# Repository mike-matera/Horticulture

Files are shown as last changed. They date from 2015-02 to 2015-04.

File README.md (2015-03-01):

Horticulture
============

Source and documentation for my project working with the Horticulture department at Cabrillo.

Autonomous Light Sensor (c) by Michael Matera

The Autonomous Light Sensor is licensed under a
Creative Commons Attribution-ShareAlike 4.0 International License.

You should have received a copy of the license along with this
work. If not, see <http://creativecommons.org/licenses/by-sa/4.0/>. 

Attributions

The PCB contains footprints from the SparkFun Eagle library. 
  https://github.com/sparkfun/SparkFun-Eagle-Libraries

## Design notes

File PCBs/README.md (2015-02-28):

This directory contains the Eagle shematic and PCB files. 

The bill of materials for the PCB can be found here: 
https://docs.google.com/spreadsheets/d/1OfI_GfA84AMtYy2GsPmqO_wkKgt9htvCScB73qxKzeg/edit?usp=sharing

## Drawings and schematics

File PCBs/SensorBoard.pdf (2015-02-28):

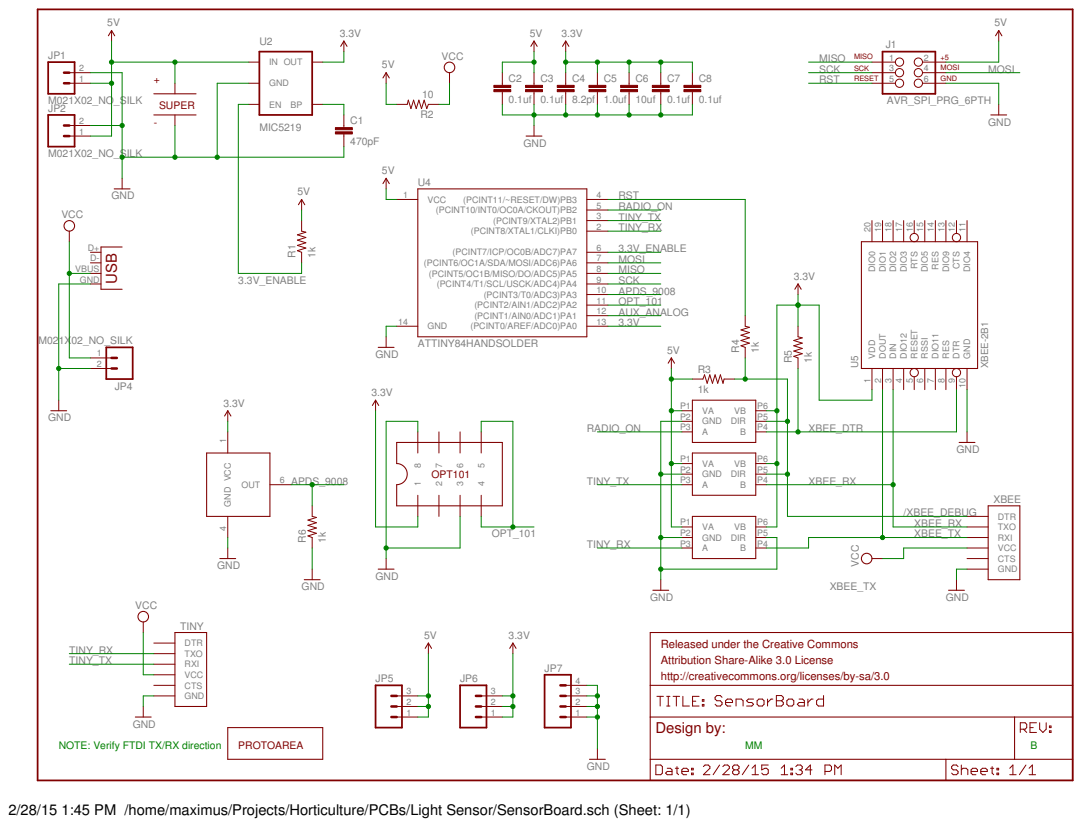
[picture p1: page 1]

Released under the Creative Commons Attribution Share-Alike 3.0 License

http://creativecommons.org/licenses/by-sa/3.0

2/28/15 1:45 PM /home/maximus/Projects/Horticulture/PCBs/Light Sensor/SensorBoard.sch (Sheet: 1/1)

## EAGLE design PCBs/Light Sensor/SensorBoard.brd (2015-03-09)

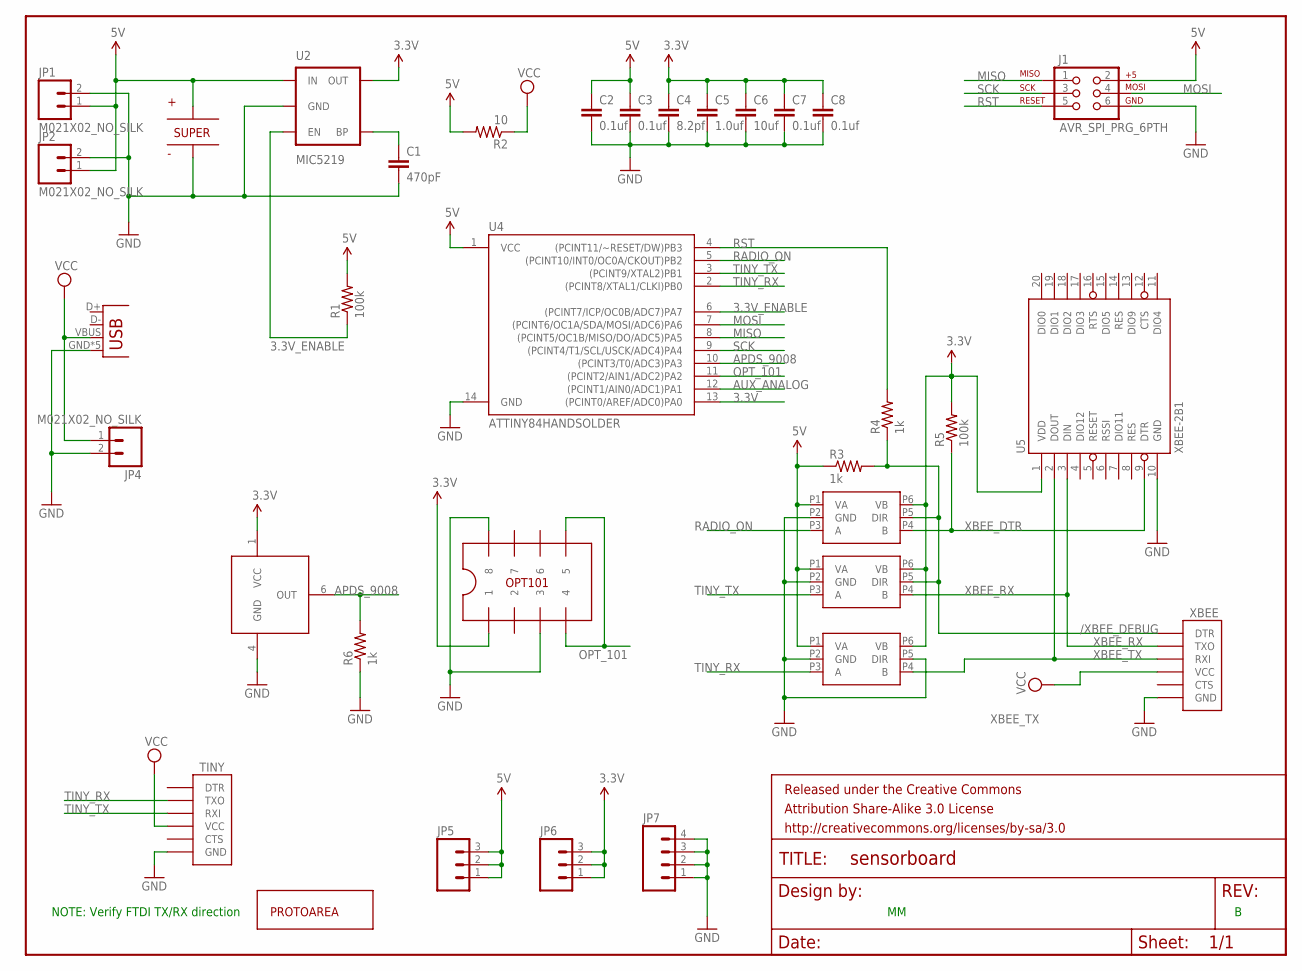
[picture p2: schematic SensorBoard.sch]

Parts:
C1: 470pF; 1210
C2, C3, C7, C8: 0.1uf; 1210
C4: 8.2pf; 1210
C5: 1.0uf; 1210
C6: 10uf; 1210
FRAME1: FRAME-LETTER; CREATIVE_COMMONS
J1: AVR_SPI_PRG_6PTH; 2X3
JP1, JP2, JP4: M021X02_NO_SILK; 1X02_NO_SILK
JP3: USBSMD; USB-MINIB
JP5, JP6: M031X03_NO_SILK; 1X03_NO_SILK
JP7: M041X04_NO_SILK; 1X04_NO_SILK
R1, R5: 100k; R1210
R2: 10; AXIAL-0.3
R3, R4, R6: 1k; R1210
TINY: FTDI_DEVICE; FTDI_DEVICE_SIDE
U1: APDS-9008
U2: MIC5219; SOT23-5
U3: OPT101TH; DIL08
U4: ATTINY84HANDSOLDER; SO14-EZ
U5: XBEE-2B1; XBEE-1
U$1: FYD0H225ZF; SUPERCAP-28.5
U$2: PROTOAREA-10X10
U$3, U$4, U$5: SN74LVC1T45; DBV-R-PDSO-G6
XBEE: FTDI_DEVICE; FTDI_DEVICE_SIDE

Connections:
3.3V: C4.1, C5.1, C6.1, C7.1, C8.1, JP6.1, JP6.2, JP6.3, R5.2, U1.1 (VCC), U2.5 (OUT), U3.1, U4.13 ((PCINT0/AREF/ADC0)PA0), U5.1 (VDD), U$3.P6 (VB), U$4.P6 (VB), U$5.P6 (VB)
3.3V_ENABLE: R1.1, U2.3 (EN), U4.6 ((PCINT7/ICP/OC0B/ADC7)PA7)
5V: C2.1, C3.1, J1.2, JP1.1, JP2.1, JP5.1, JP5.2, JP5.3, R1.2, R2.P$2 (2), R3.1, U2.1 (IN), U4.1 (VCC), U$1.+, U$3.P1 (VA), U$4.P1 (VA), U$5.P1 (VA)
/XBEE_DEBUG: R3.2, R4.1, U$3.P5 (DIR), U$4.P5 (DIR), XBEE.P$1 (DTR)
APDS_9008: R6.2, U1.6 (OUT), U4.10 ((PCINT3/T0/ADC3)PA3)
AUX_ANALOG: U4.12 ((PCINT1/AIN0/ADC1)PA1)
GND: C1.2, C2.2, C3.2, C4.2, C5.2, C6.2, C7.2, C8.2, J1.6, JP1.2, JP2.2, JP3.GND, JP3.MTN1 (GND), JP3.MTN2 (GND), JP3.MTN3 (GND), JP3.MTN4 (GND), JP4.2, JP7.1, JP7.2, JP7.3, JP7.4, R6.1, TINY.P$6 (GND), U1.4 (GND), U2.2 (GND), U3.3, U3.8, U4.14 (GND), U5.10 (GND), U$1.-, U$3.P2 (GND), U$4.P2 (GND), U$5.P2 (GND), U$5.P5 (DIR), XBEE.P$6 (GND)
MISO: J1.1, U4.8 ((PCINT5/OC1B/MISO/DO/ADC5)PA5)
MOSI: J1.4, U4.7 ((PCINT6/OC1A/SDA/MOSI/ADC6)PA6)
unnamed: C1.1, U2.4 (BP)
OPT_101: U3.4, U3.5, U4.11 ((PCINT2/AIN1/ADC2)PA2)
RADIO_ON: U4.5 ((PCINT10/INT0/OC0A/CKOUT)PB2), U$3.P3 (A)
RST: J1.5, R4.2, U4.4 ((PCINT11/~RESET/DW)PB3)
SCK: J1.3, U4.9 ((PCINT4/T1/SCL/USCK/ADC4)PA4)
TINY_RX: TINY.P$2 (TXO), U4.2 ((PCINT8/XTAL1/CLKI)PB0), U$5.P3 (A)
TINY_TX: TINY.P$3 (RXI), U4.3 ((PCINT9/XTAL2)PB1), U$4.P3 (A)
VCC: JP3.VBUS, JP4.1, R2.P$1 (1), TINY.P$4 (VCC), XBEE.P$4 (VCC)
XBEE_DTR: R5.1, U5.9 (DTR), U$3.P4 (B)
XBEE_RX: U5.3 (DIN), U$4.P4 (B), XBEE.P$2 (TXO)
XBEE_TX: U5.2 (DOUT), U$5.P4 (B), XBEE.P$3 (RXI)

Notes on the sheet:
NOTE: Verify FTDI TX/RX direction

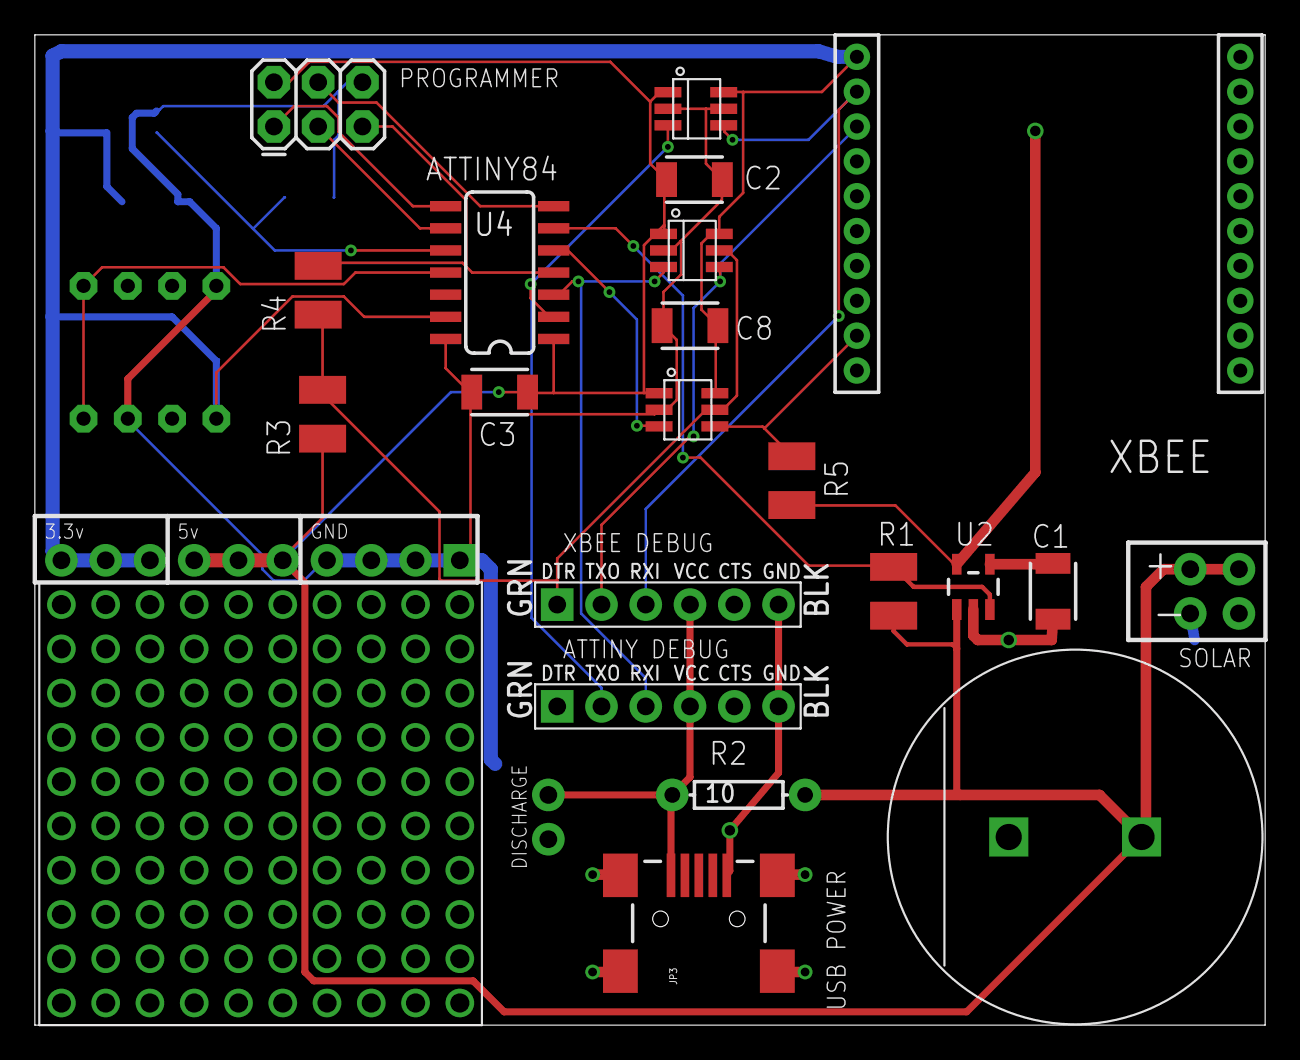
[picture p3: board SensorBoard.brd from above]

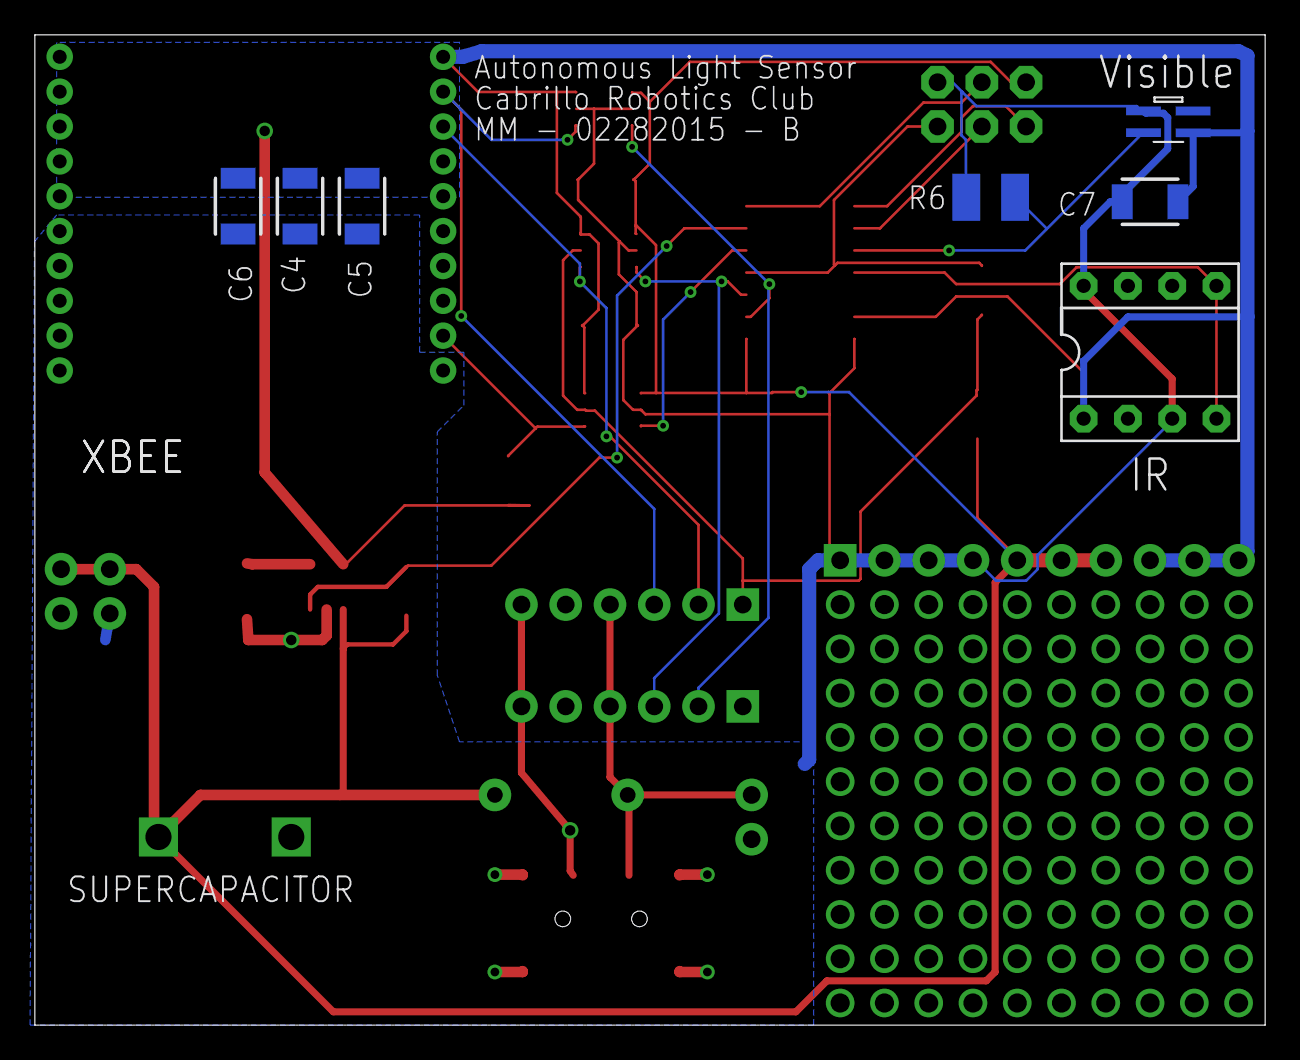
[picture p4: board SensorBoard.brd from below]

Board: 2 copper layers, 70.6 x 56.8 mm, 35 parts (7 on the bottom side), 19 nets.

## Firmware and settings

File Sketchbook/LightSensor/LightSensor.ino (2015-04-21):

#include <SoftwareSerial.h>
#include <avr/sleep.h>
#include <avr/power.h>
#include <avr/wdt.h>
#include <avr/interrupt.h>

#define TX               9
#define RX              10
#define SLEEP            8
#define ENABLE3V3        7 
#define OPT_101          2
#define APDS_9008        3
#define SLEEP_VOLTAGE  4.7 
#define WAKE_VOLTAGE   4.8 
#define DEBUG_PIN        5


SoftwareSerial ser(RX, TX);

class PowerManager {
public:

  enum PowerState { 
    radio, 
    running, 
    sleeping,
    boot
  }; 
  
  PowerManager() {
    // Setup the 3.3v control pin and keep 3.3v off until we know
    // how much charge we have available...
    pinMode(ENABLE3V3, OUTPUT);
    // Setup the XBEE DTR sleep pin and keep the XBEE asleep
    pinMode(SLEEP, OUTPUT);
    
    // This is how we want to sleep when we do.
    // Power down everything, wake up from WDT
    set_sleep_mode(SLEEP_MODE_PWR_DOWN); 
    sleep_enable();
    setState(boot);
  }
    
  ~PowerManager() {
  }

  PowerState getState() {
    return state; 
  }
  
  void setState(PowerState s) {
    if (s == radio) {
      on3v3();
      onRadio();
    }else if (s == running) {
      on3v3();
      offRadio();
    }else if (s == sleeping) {
      off3v3();
      offRadio();
    }else if (s == boot) {
      off3v3();
      offRadio();
    }
    state = s;
  }

  // Respond to the WDT. Do not call "main" code here. 
  // The snooze() statement in the loop function will 
  // return after this call returns. Determine how much
  // energy we have and what to do about it. 
  // NOTE: using the ADC seems unrelaible in this context, 
  // it seems like I cna't switch input/reference, why?
  void wake() {
  }
  
  // Put the processor to sleep. Power down most units so it's 
  // not running code any longer. This saves TONS of power. Only
  // The watchdog timer can wake us up from here. Anytime it goes
  // off the WDT ISR will run and this function will return.
  void snooze() {
    ADCSRA &= ~(1<<ADEN); 
    
    int prescale;
    // Prescaler values: 0=16ms, 1=32ms, 2=64ms, 3=128ms, 4=250ms, 5=500ms, 6=1sec, 7=2sec, 8=4sec, 9=8sec
    if (state == sleeping) {
      prescale = 9; // wake up as infreqently as possible (8 seconds)
    }else{
      prescale = 6; // wake up every second
    }
    byte bb = prescale & 7; 
    if (prescale > 7) bb |= (1<<5); // Set the special 5th bit if necessary

    // This order of commands is important and cannot be combined
    MCUSR &= ~(1<<WDRF); // Clear the watch dog reset
    WDTCSR |= (1<<WDCE) | (1<<WDE); // Set WD_change enable, set WD enable
    WDTCSR = bb; // Set new watchdog timeout value
    WDTCSR |= _BV(WDIE); //Set the interrupt enable, this will keep unit from resetting after each int

    sleep_enable();

    // Disable ADC
    ADCSRA &= ~(1<<ADEN); 
    
    digitalWrite(DEBUG_PIN, LOW);
    sleep_mode(); 
    digitalWrite(DEBUG_PIN, HIGH);
    
    // Enable ADC
    ADCSRA |= (1<<ADEN); 
    sleep_disable();
    
    updateVcc();
    if ((state == boot || state == sleeping) && supply >= WAKE_VOLTAGE) {
      setState(running);
    }else if (state == boot || state == running || state == radio) {
      if (supply <= SLEEP_VOLTAGE) {
        // If we are in radio this might break the transmission
        // That's okay because we're out of power!
        setState(sleeping);
      }
    }
  }

  // Read VCC assign it to vcc
  float getVcc() {
    return supply;
  }
  
private:
  
  // Turn off XBEE using the DTR pin
  void offRadio() {
    digitalWrite(SLEEP, HIGH);
  }

  // Turn on XBEE using the DTR pin
  void onRadio() {
    digitalWrite(SLEEP, LOW);
    delay(100);
  }

  void off3v3() {
    digitalWrite(ENABLE3V3, LOW);  
  }

  void on3v3() {
    digitalWrite(ENABLE3V3, HIGH);
  }

  // Read VCC assign it to vcc
  void updateVcc() {
    ADMUX = 0x21;
    delay(2);
    ADCSRA |= 1<<ADSC; // Convert
    while (bit_is_set(ADCSRA,ADSC));
    supply = 1126.4 / ((float) ADC); 
  }

  PowerState state;     
  float supply;
};

PowerManager pm; 

ISR(WDT_vect) {
  pm.wake();
}

uint16_t readIR() {
  analogReference(EXTERNAL);
  delay(10);
  return analogRead(OPT_101);
}

uint16_t readVisible() {
  analogReference(EXTERNAL);
  delay(10);
  return analogRead(APDS_9008);
}

void setup() {
  ser.begin(9600);
  pinMode(DEBUG_PIN, OUTPUT);
}

void loop() 
{
  static int tick = 0; 
  static uint32_t odometer = 0; 

  pm.snooze();

  tick++;

  if (pm.getState() == PowerManager::running) {  
    uint16_t IR_reading = readIR();
    uint16_t visible_reading = readVisible();  
    odometer += IR_reading;
    if (tick > 1) {
      pm.setState(PowerManager::radio);
      ser.print("VCC: ");
      ser.print(pm.getVcc());
      ser.print(" IR: ");
      ser.print(IR_reading);
      ser.print(" Visible: ");
      ser.print(visible_reading);
      ser.print(" ODO: ");
      ser.println(odometer);
      pm.setState(PowerManager::running);
      tick = 0;
    }
  }
}

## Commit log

2014-09-23 Initial version of the light sensor
    [SensorBoard.sch]
2014-10-03 Changed to using breadboard friendly symbols
    [SensorBoard.sch]
2014-12-01 Added level translator, jumpers
    [SensorBoard.sch]
2014-12-08 Added protection, pinswap level shift, proto area
    [SensorBoard.sch]
2014-12-08 Early Board
    [SensorBoard.brd]
2014-12-10 Added caps, back to DIPs on everything, fixups, screw holes
    [SensorBoard.sch]
2014-12-10 Working layout
    [SensorBoard.brd]
2014-12-20 Version taped out for rev A
    [SensorBoard.brd, SensorBoard.sch]
2015-02-17 Fixes: - Changed to ATTiny84 for more pins - Changed to enable/disable 3.3v LDO to avoid droop conditions
    [SensorBoard.sch]
2015-02-17 Initial relayout for the new components
    [SensorBoard.brd]
2015-02-21 Working on updates
    [SensorBoard.brd, SensorBoard.sch]
2015-02-23 Incremental updates
    [SensorBoard.brd, SensorBoard.sch]
2015-02-24 Still routing and placing
    [SensorBoard.brd, SensorBoard.sch]
2015-02-27 Almost finished with layout
    [SensorBoard.brd, SensorBoard.sch]
2015-02-28 Update and rename PCBs to PCBs/README.md
2015-02-28 Rev. B layout complete, design review soon
    [SensorBoard.brd, SensorBoard.sch]
2015-03-01 Grounded USB shield
    [SensorBoard.brd, SensorBoard.sch]
2015-03-09 Changed pullups to 100K to save power
    [SensorBoard.brd, SensorBoard.sch]
2015-04-21 Mostly working with powerdown

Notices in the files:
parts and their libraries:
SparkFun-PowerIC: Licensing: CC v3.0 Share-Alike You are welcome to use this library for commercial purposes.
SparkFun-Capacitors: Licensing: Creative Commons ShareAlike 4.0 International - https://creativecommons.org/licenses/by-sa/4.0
